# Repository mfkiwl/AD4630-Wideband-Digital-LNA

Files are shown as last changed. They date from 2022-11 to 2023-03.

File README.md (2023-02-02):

# AD4630 Wideband Digital LNA
## Introduction
Output noise is an important metric when it comes to evaluating the performance of precision voltage references (temperature coefficient and stability being others). Of particular interest is the frequency band between 0.1Hz and 10Hz. Most long-scale integrating ADCs feature measurement periods that lie in this band, so the internal reference should ideally have noise lower than measurement resolution over this time period. To measure noise in this band, an amplifier, itself having low noise, is needed. Appropriate filtering is also desired to keep out excess noise (of other frequencies) from contaminating the band of interest. 
## Project Motivation
This idea was originally proposed to me by [Marco Reps](https://www.youtube.com/@reps), which was in turn based on an idea [Mark](https://github.com/macaba) had told him about - a digital sampler that would send raw samples to a computer program that would filter to the required bandwidth digitally. Given the 2Msps sample rate of the AD4630, the upper frequency limit could be expanded to several kilohertz. The addition of a chopper preamp would also greatly reduce input noise. DC-coupling the input and adding a few preamps in parallel would also make a crude nanovoltmeter. This project is intended mainly to explore the AD4630 itself, and evaluate possible front end circuits.
### Goals:
- Wideband sampling and digitally filtering samples to desired bandwidth
- Ultralow 1/f corner front end with AC and DC paths for noise and nanovolt measurements (TBD)
- Optically isolated digital and analog sections: This is achieved easiest using a separate controller for front-end side, and using something like a UART isolator and a UART-USB bridge on the other side. 
- Battery powered (front end at least, digital section USB powered): This one might be a bit challenging, for example, what kind of batteries will be used? What voltages to power the front end with? Single ended or bipolar?
### Challenges: 
- Evaluating noise performance
- Implementing optical isolation and battery power
## Usage
### Specifications:
- 10mHz to 10kHz input bandwidth    [calculated]
- x200000 (106dB)                   [calculated]
- ~3.5nV/rtHz noise floor (full BW) [calculated]
## List of Files
- Hardware: KiCAD PCB files.
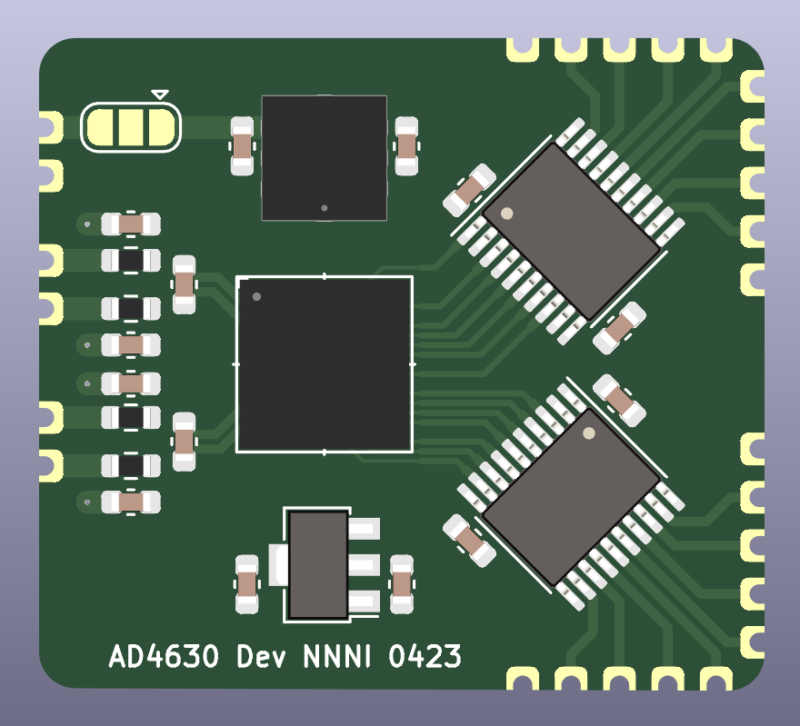
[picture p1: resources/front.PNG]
Prototype PCB layout

- Software: [under construction]
  - Simulation: LTspice .asc file.
- Resources: Infographics.
## Application Examples
[under construction]
- The LNA outputs raw samples that can be stored in a .csv file and interpreted by an [NSD](https://github.com/macaba/NSD) program. 
## Notes
- The AD4630 is pin-compatible with the AD4030, which opens up some interesting possibilities in the future.
- The input stage consists of a Sallen-Key filter that filters out frequencies below 10mHz while providing a gain of 330. It is possible to have gain and filtering in the same stage because of the low Thevenin resistance of the amplifier feedback resistors. The input filter/gain stage is followed by another x330 gain stage, which in turn is followed by a fully-differential amplifier (x2) to convert the input swing to a differential swing for the ADC. It should theoretically be possible to cancel reference noise by setting fully differential amplifier common mode voltage to 1/2\*Vref as well as referencing one of the ADC differential inputs to 1/2\*Vref. Overall gain is 200000.

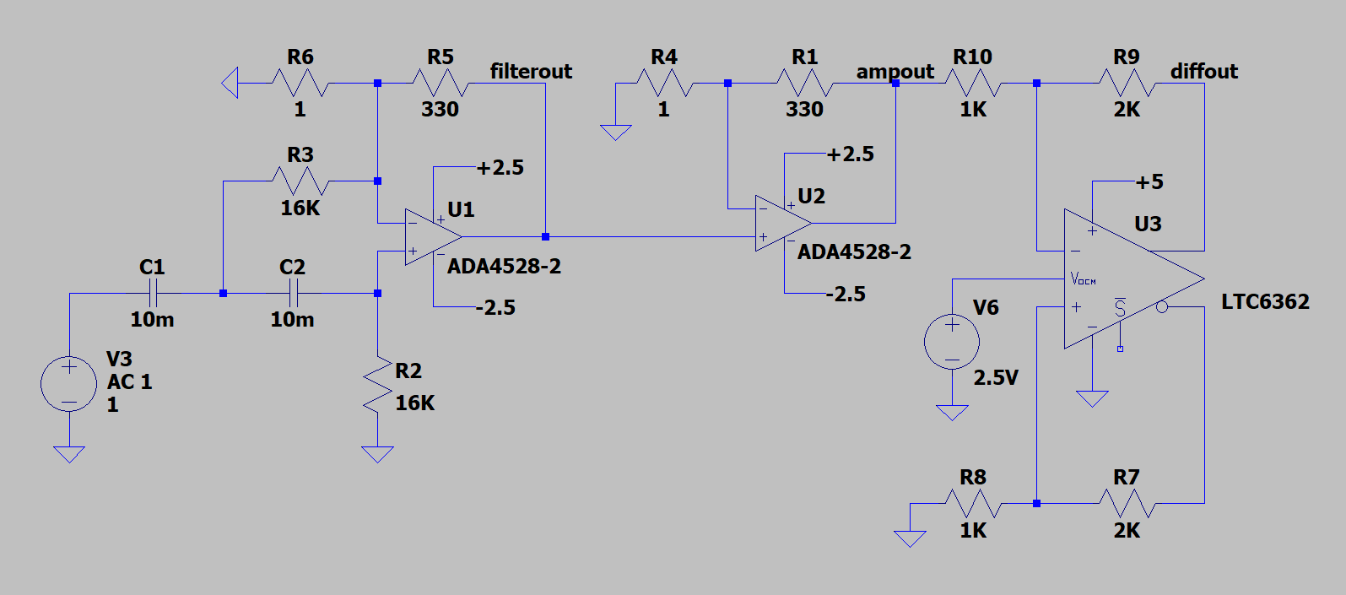
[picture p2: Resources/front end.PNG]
Infographic

## Links
- https://www.analog.com/media/en/technical-documentation/data-sheets/ad4630-24_ad4632-24.pdf
- https://www.analog.com/media/en/technical-documentation/data-sheets/ada4528-1_4528-2.pdf
- https://www.analog.com/media/en/technical-documentation/data-sheets/6362fa.pdf
- http://sim.okawa-denshi.jp/en/OPseikiHikeisan.htm
- http://www.dicks-website.eu/low_noise_amp_part1/part1.html

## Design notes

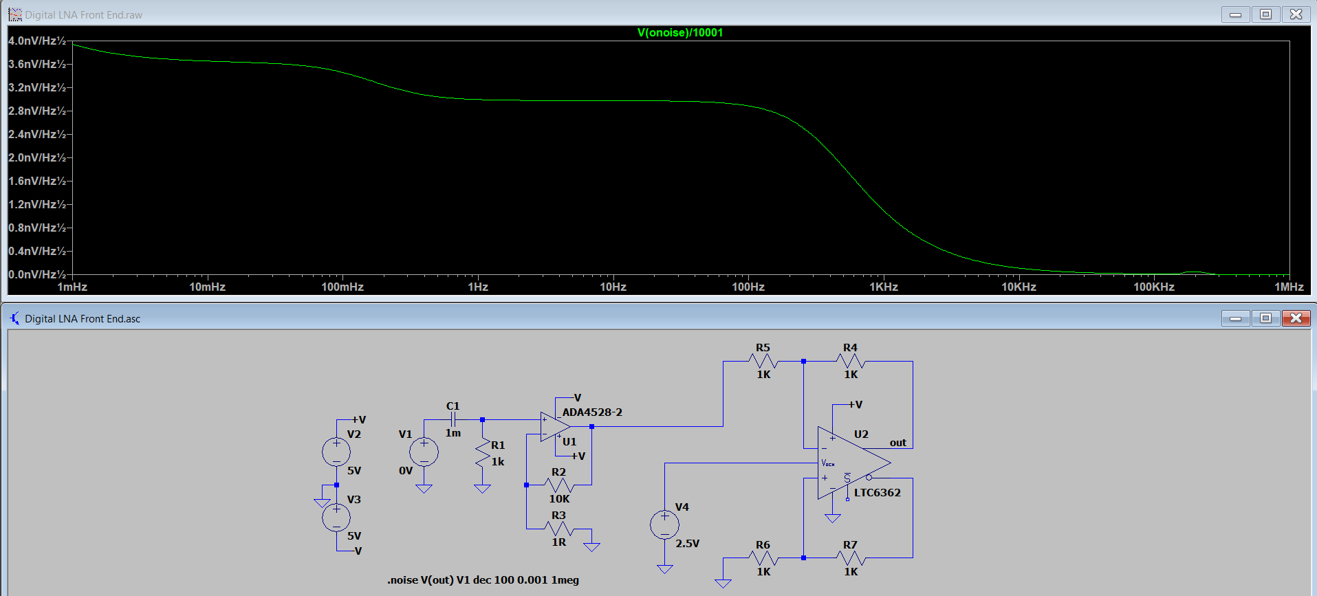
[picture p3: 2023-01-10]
Resources/noise10001.png

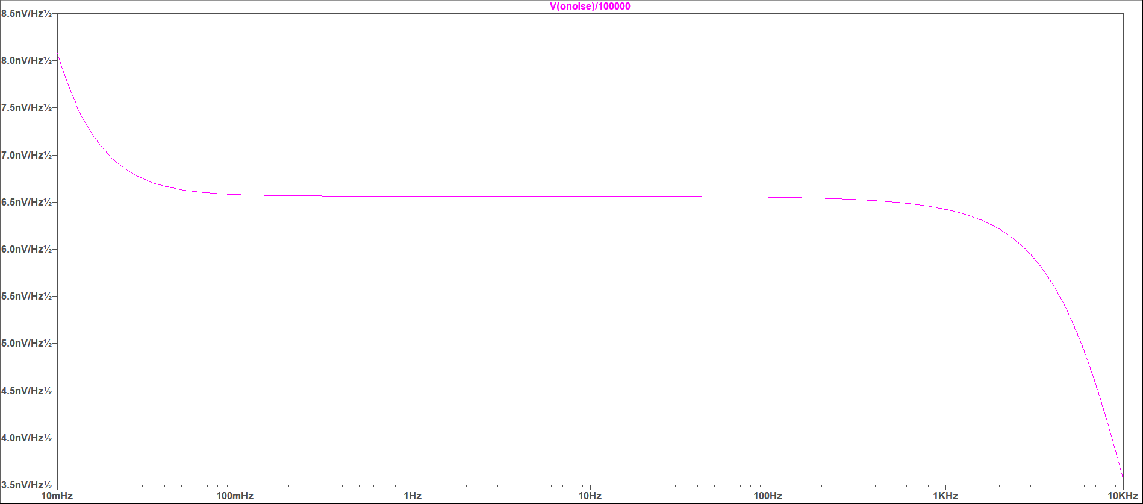
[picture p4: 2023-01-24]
Resources/bandwidth noise simulation.png

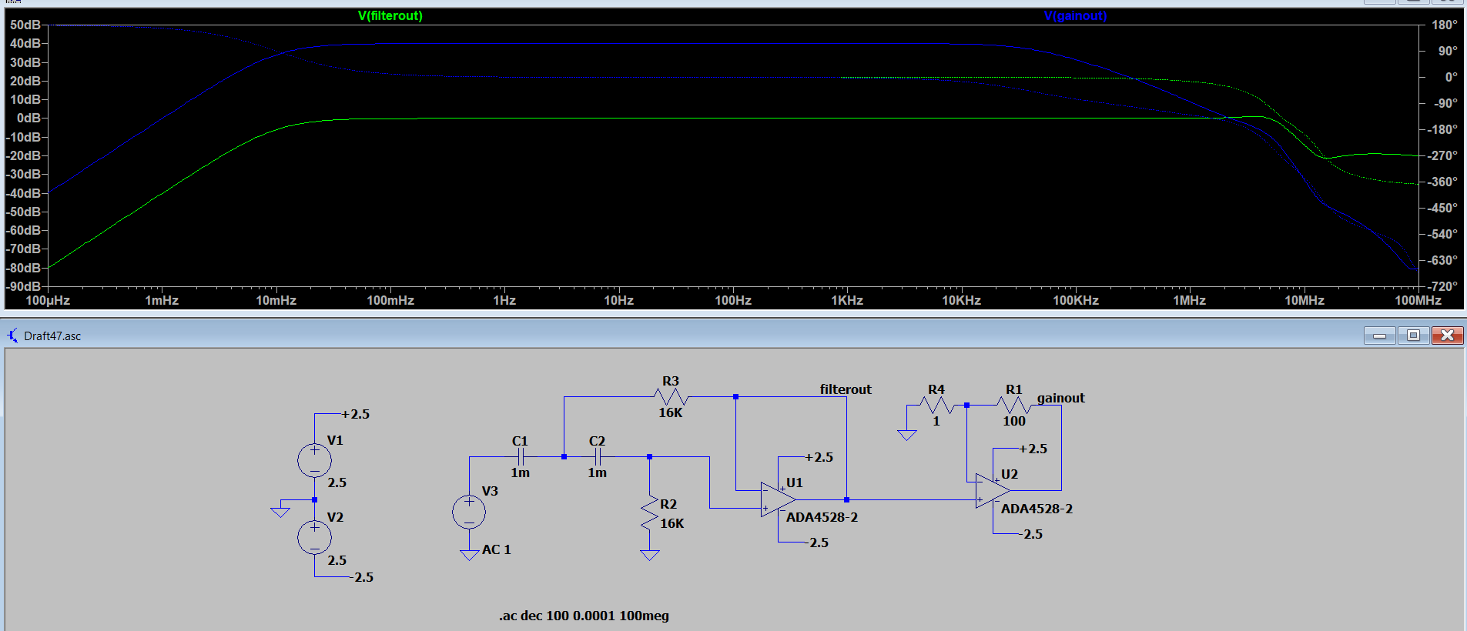
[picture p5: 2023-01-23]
Resources/filterandgain.png

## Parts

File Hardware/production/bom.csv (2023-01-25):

Designator | Footprint | Quantity | Value | LCSC Part #
C1, C11, C12, C13, C14, C2, C3, C4 | C_0603_1608Metric | 8 | 10uF
C10, C5, C6, C7, C8, C9 | C_0603_1608Metric | 6 | C
J1, J4 | PinHeader_1x02_P2.54mm_Vertical | 2 | IN0
J2 | PinHeader_1x02_P2.54mm_Vertical | 1 | IN1
J3, J5, J6, J7 | PinHeader_1x05_P2.00mm_Vertical | 4 | IO
R1, R2, R3, R4 | R_0603_1608Metric | 4 | R
U1 | AD4630-24BBCZ | 1 | AD4630-24BBCZ
U2 | SOT-89-3 | 1 | AMS1117-1.8
U3, U4 | TSSOP-20_4.4x6.5mm_P0.65mm | 2 | TXS0108EPW
U6 | LTC6655BHLS8-5-PBF | 1 | LTC6655

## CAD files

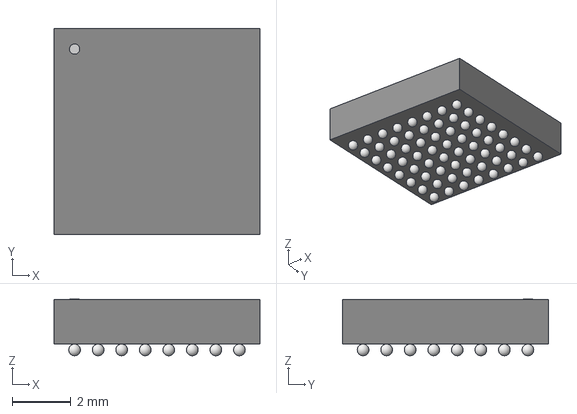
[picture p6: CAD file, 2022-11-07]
Hardware/AD4630-24BBCZ/AD4630.step
7.00 x 7.00 x 1.92 mm

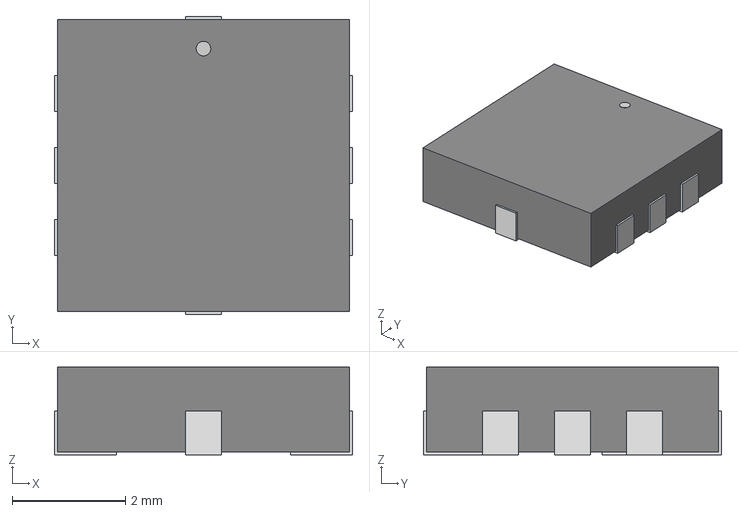
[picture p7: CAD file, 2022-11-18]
Hardware/LTC6655/LTC6655.step
5.26 x 5.26 x 1.55 mm

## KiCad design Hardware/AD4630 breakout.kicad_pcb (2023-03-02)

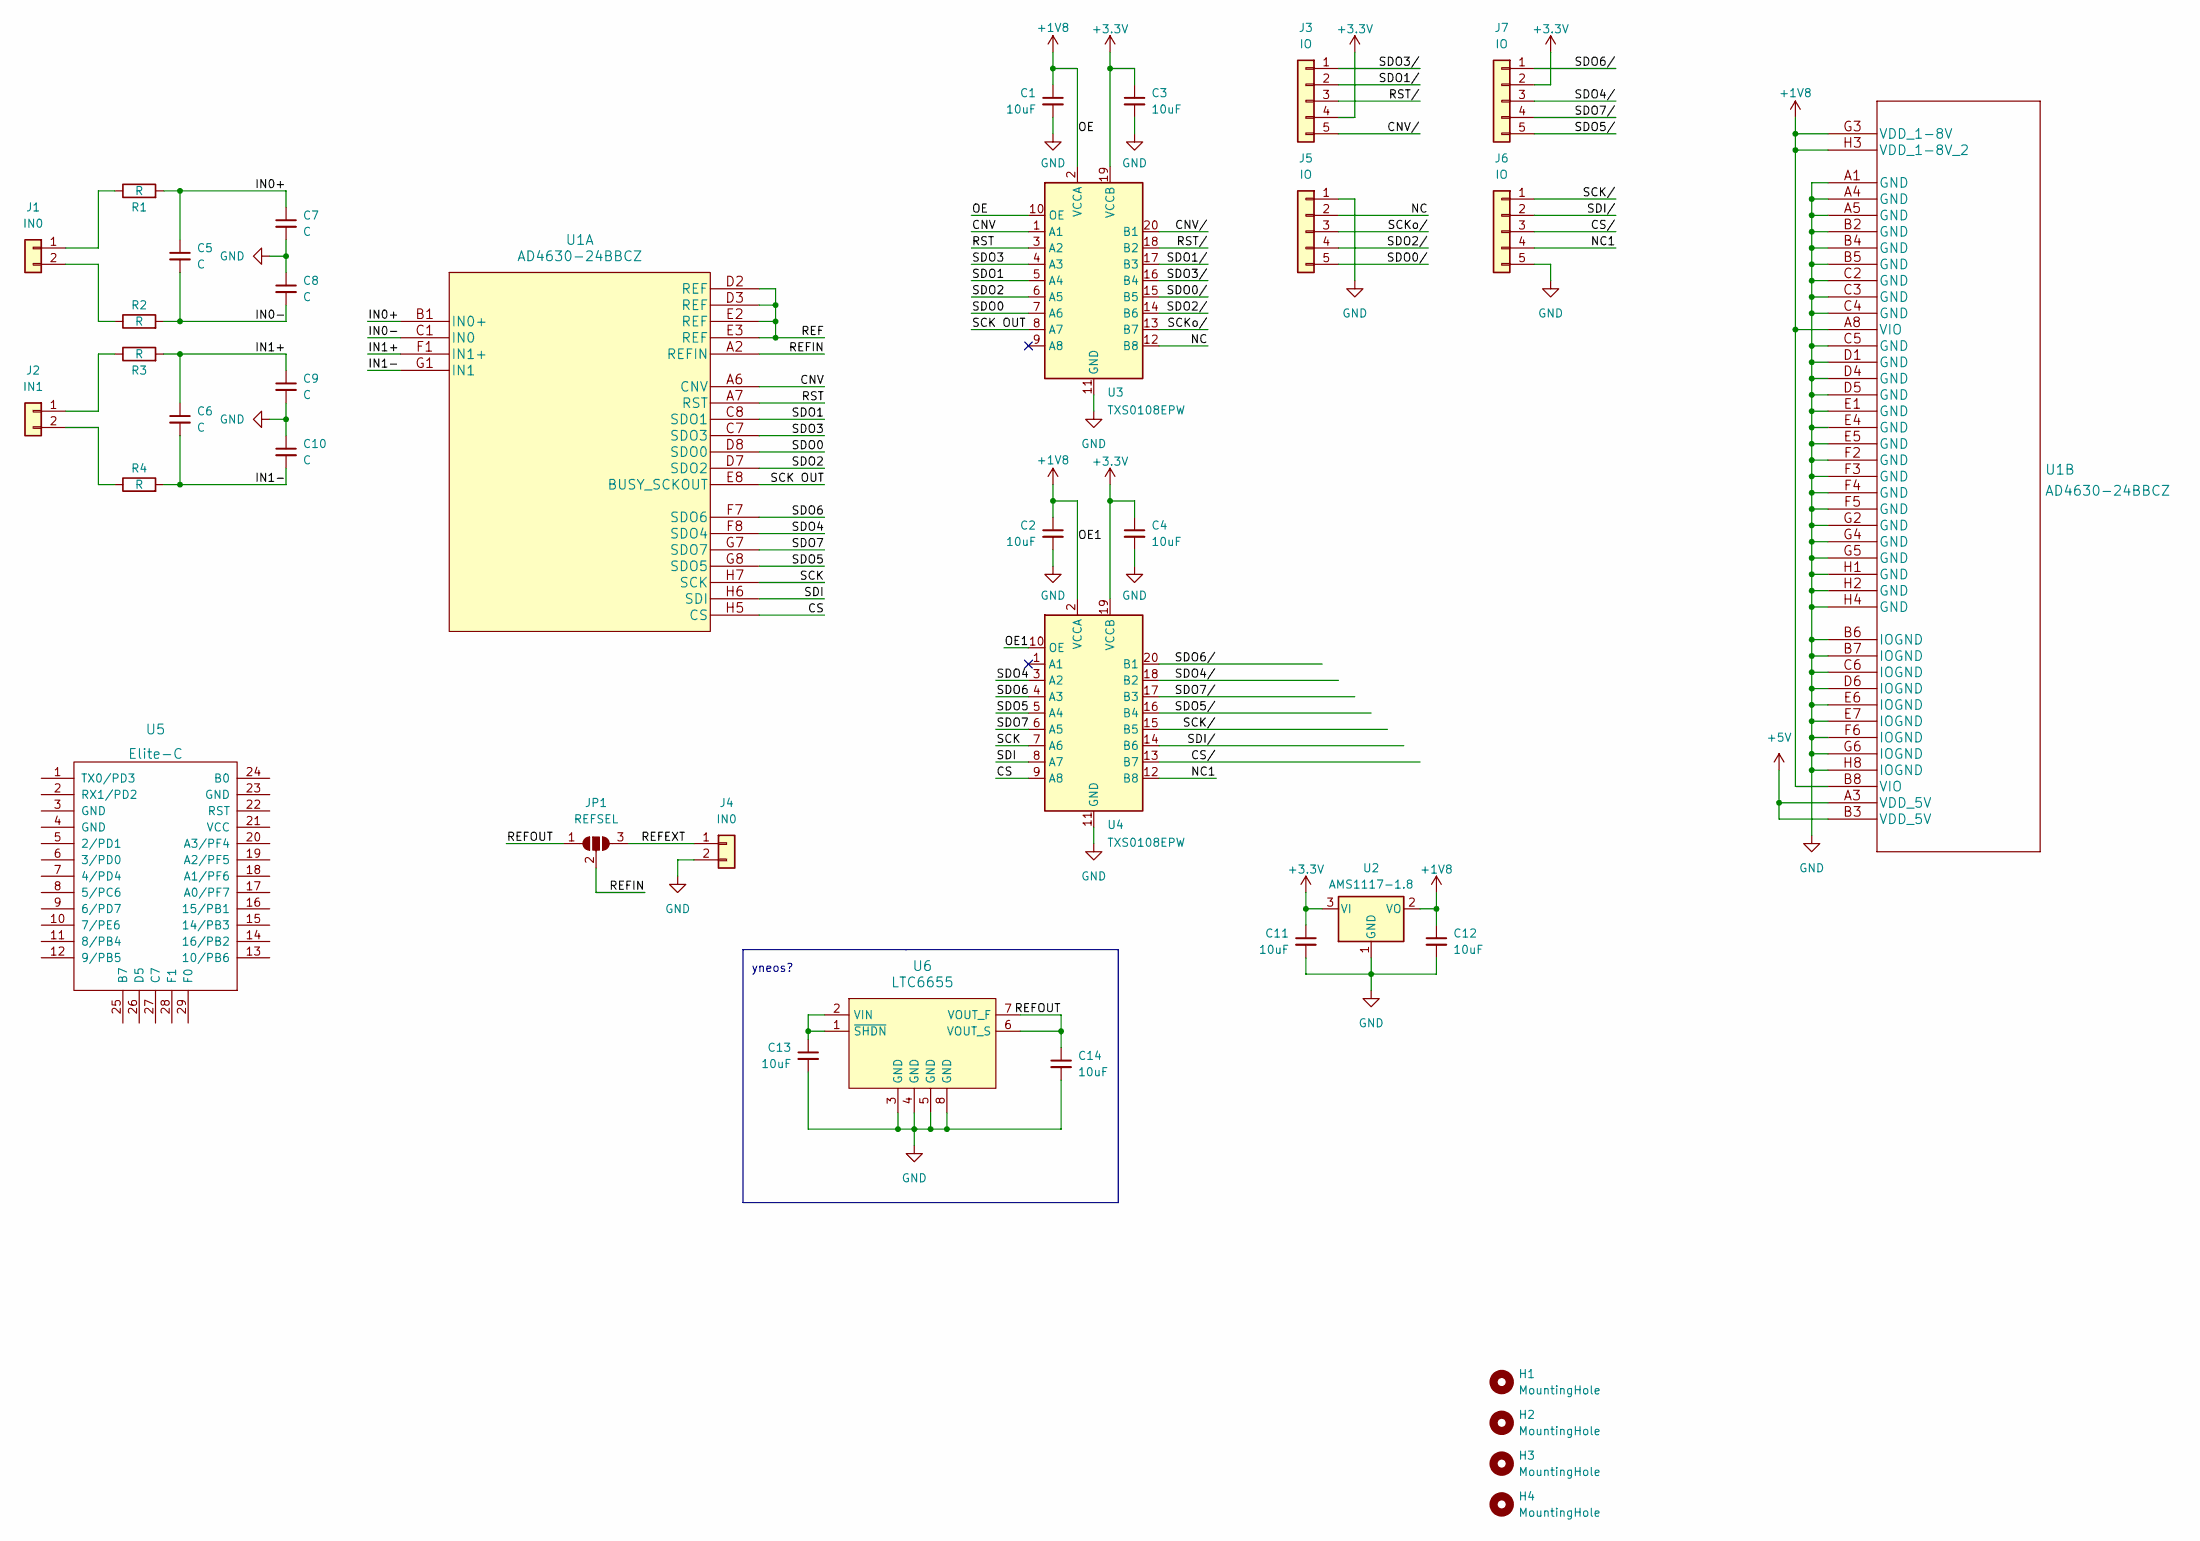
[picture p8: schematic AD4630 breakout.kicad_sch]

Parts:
C1, C2, C3, C4, C11, C12, C13, C14: 10uF; C_0603_1608Metric
C5, C6, C7, C8, C9, C10: C; C_0603_1608Metric
H1, H2, H3, H4: MountingHole; MountingHole_3.2mm_M3_Pad_Via
J1, J4: IN0; PinHeader_1x02_P2.00mm_Vertical
J2: IN1; PinHeader_1x02_P2.00mm_Vertical
J3, J5, J6, J7: IO; PinHeader_1x05_P2.00mm_Vertical
JP1: REFSEL; SolderJumper-3_P1.3mm_Open_RoundedPad1.0x1.5mm
R1, R2, R3, R4: R; R_0603_1608Metric
U1: AD4630-24BBCZ
U2: AMS1117-1.8; SOT-89-3
U3, U4: TXS0108EPW; TSSOP-20_4.4x6.5mm_P0.65mm
U5: Elite-C; Elite-C-castellated-29pin-holes
U6: LTC6655; LTC6655BHLS8-5-PBF

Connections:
+1V8: C1.1, C2.1, C12.1, U1.A8 (VIO), U1.B8 (VIO), U1.G3 (VDD_1-8V), U1.H3 (VDD_1-8V_2), U2.2 (VO), U3.2 (VCCA), U3.10 (OE), U4.2 (VCCA), U4.10 (OE)
+3V3: C3.1, C4.1, C11.1, J3.4, J7.2, U2.3 (VI), U3.19 (VCCB), U4.19 (VCCB)
+5V: U1.A3 (VDD_5V), U1.B3 (VDD_5V)
/CNV: U1.A6 (CNV), U3.1 (A1)
/CNV/: J3.5, U3.20 (B1)
/CS: U1.H5 (CS), U4.9 (A8)
/CS/: J6.3, U4.13 (B7)
/IN0+: C5.1, C7.1, R1.2, U1.B1 (IN0+)
/IN0-: C5.2, C8.2, R2.2, U1.C1 (IN0)
/IN1+: C6.1, C9.1, R3.2, U1.F1 (IN1+)
/IN1-: C6.2, C10.2, R4.2, U1.G1 (IN1)
/NC: J5.2, U3.12 (B8)
/NC1: J6.4, U4.12 (B8)
/REF: U1.D2 (REF), U1.D3 (REF), U1.E2 (REF), U1.E3 (REF)
/REFEXT: J4.1, JP1.3 (B)
/REFIN: JP1.2 (C), U1.A2 (REFIN)
/REFOUT: C14.1, JP1.1 (A), U6.6 (VOUT_S), U6.7 (VOUT_F)
/RST: U1.A7 (RST), U3.3 (A2)
/RST/: J3.3, U3.18 (B2)
/SCK: U1.H7 (SCK), U4.7 (A6)
/SCK OUT: U1.E8 (BUSY_SCKOUT), U3.8 (A7)
/SCKo/: J5.3, U3.13 (B7)
/SCK/: J6.1, U4.15 (B5)
/SDI: U1.H6 (SDI), U4.8 (A7)
/SDI/: J6.2, U4.14 (B6)
/SDO0: U1.D8 (SDO0), U3.7 (A6)
/SDO0/: J5.5, U3.15 (B5)
/SDO1: U1.C8 (SDO1), U3.5 (A4)
/SDO1/: J3.2, U3.17 (B3)
/SDO2: U1.D7 (SDO2), U3.6 (A5)
/SDO2/: J5.4, U3.14 (B6)
/SDO3: U1.C7 (SDO3), U3.4 (A3)
/SDO3/: J3.1, U3.16 (B4)
/SDO4: U1.F8 (SDO4), U4.3 (A2)
/SDO4/: J7.3, U4.18 (B2)
/SDO5: U1.G8 (SDO5), U4.5 (A4)
/SDO5/: J7.5, U4.16 (B4)
/SDO6: U1.F7 (SDO6), U4.4 (A3)
/SDO6/: J7.1, U4.20 (B1)
/SDO7: U1.G7 (SDO7), U4.6 (A5)
/SDO7/: J7.4, U4.17 (B3)
GND: C1.2, C2.2, C3.2, C4.2, C7.2, C8.1, C9.2, C10.1, C11.2, C12.2, C13.2, C14.2, J4.2, J5.1, J6.5, U1.A1 (GND), U1.A4 (GND), U1.A5 (GND), U1.B2 (GND), U1.B4 (GND), U1.B5 (GND), U1.B6 (IOGND), U1.B7 (IOGND), U1.C2 (GND), U1.C3 (GND), U1.C4 (GND), U1.C5 (GND), U1.C6 (IOGND), U1.D1 (GND), U1.D4 (GND), U1.D5 (GND), U1.D6 (IOGND), U1.E1 (GND), U1.E4 (GND), U1.E5 (GND), U1.E6 (IOGND), U1.E7 (IOGND), U1.F2 (GND), U1.F3 (GND), U1.F4 (GND), U1.F5 (GND), U1.F6 (IOGND), U1.G2 (GND), U1.G4 (GND), U1.G5 (GND), U1.G6 (IOGND), U1.H1 (GND), U1.H2 (GND), U1.H4 (GND), U1.H8 (IOGND), U2.1 (GND), U3.11 (GND), U4.11 (GND), U6.3 (GND), U6.4 (GND), U6.5 (GND), U6.8 (GND)
unnamed: C13.1, U6.1 (~SHDN), U6.2 (VIN)
unnamed: J1.1, R1.1
unnamed: J1.2, R2.1
unnamed: J2.1, R3.1
unnamed: J2.2, R4.1

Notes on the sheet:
yneos?

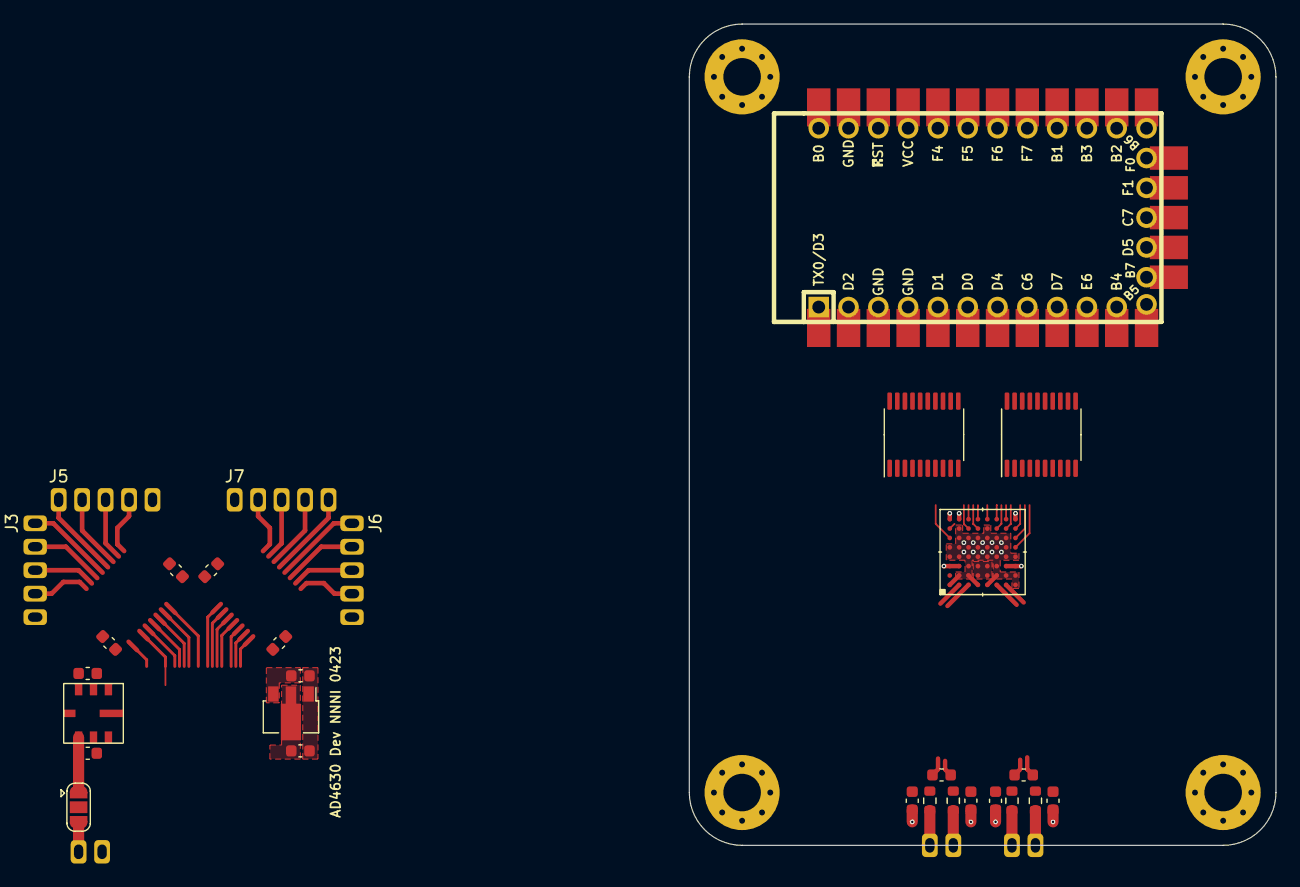
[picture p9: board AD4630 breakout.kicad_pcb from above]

Board: 4 copper layers, 50.0 x 70.0 mm, 36 parts (0 on the bottom side), 47 nets.

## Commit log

2022-11-07 Added PCB Files
    [AD4630 breakout.kicad_pcb, AD4630 breakout.kicad_sch, BC_64_8_ADI.step]
2022-11-07 Updated PCB
    [AD4630 breakout.kicad_pcb, AD4630 breakout.kicad_sch]
2022-11-18 PCB updated
    [AD4630 breakout.kicad_pcb, AD4630 breakout.kicad_sch, AD4630.step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]
2022-11-26 Finished PCB
    [AD4630 breakout.kicad_pcb, AD4630 breakout.kicad_sch]
2023-01-08 updated files
    [AD4630 breakout.kicad_pcb, AD4630 breakout.kicad_sch, AD4630.step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]
2023-01-23 added infographic
    [AD4630 breakout.kicad_pcb]

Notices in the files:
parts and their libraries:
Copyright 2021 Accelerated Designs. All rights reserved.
